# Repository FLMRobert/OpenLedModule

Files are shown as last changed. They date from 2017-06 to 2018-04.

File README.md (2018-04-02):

# OpenLedModule
OpenLedModule - an Open Hardware LED module project

The OpenLedModule project provides Open Hardware LED modules for everyone! 

With OpenLedModule, you can easily build your own lighting fixture - just follow these steps:

***

**Step 1**: Choose a basic LED lamp model that fits your needs

_Example_: choose [40FLATLED](https://github.com/FLMRobert/OpenLedModule/wiki/Lamps-40FLATLED) - a ceiling lamp that is as bright as two 60W light bulbs.

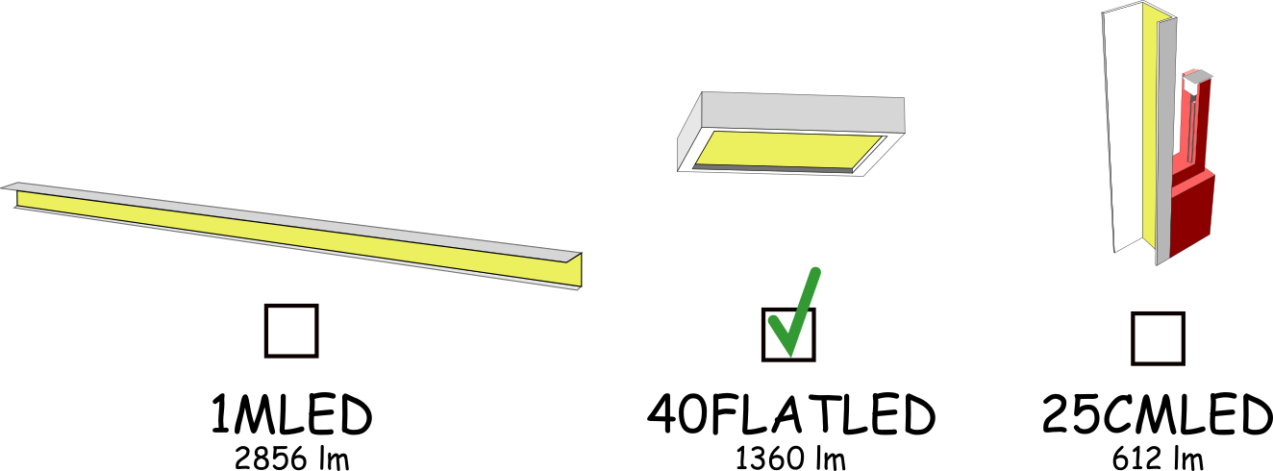
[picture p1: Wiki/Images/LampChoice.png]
Choose Lamp Model


***

**Step 2**: Check which LED Module is required to build the lamp model

_Example_: for lamp 40FLATLED, [Module 2](https://github.com/FLMRobert/OpenLedModule/wiki/Modules---Module-2) is required

***

**Step 3**: Order the required number of LED Modules from a PCB (circuit board) manufacturer of your choice

_Example_: [order](https://github.com/FLMRobert/OpenLedModule/wiki/Ordering-Overview) five Module 2 PCBs to build lamp 40FLATLED.

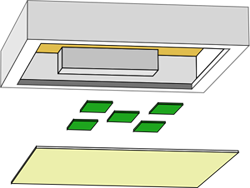
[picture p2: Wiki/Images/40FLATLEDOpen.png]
Check Lamp Module


***

**Step 4**: Order the parts (LEDs, resistors and pin headers) that are required for assembling the LED module

_Example_: the [Data Sheet of Module 2](https://github.com/FLMRobert/OpenLedModule/wiki/DataSheets-Modules-Module-2) lists all parts that are required for module assembly. For Module 2 you need to order eight [OSRAM Duris E5](https://github.com/FLMRobert/OpenLedModule/wiki/LEDs-OSRAM-Duris-E5) LEDs and one 30 Ohm resistor. This totals to 40 LEDs and five resistors for the five modules of lamp 40FLATLED. In addition to that you need nine pin headers that are required for connecting the module connector cables. 

***

**Step 5**: Solder your LED modules  
If you don't have reflow soldering equipment: go to a makerspace of your choice and solder it there.
Many makerspaces own a temperature-controlle "pizza oven" for reflow soldering.
With this oven, you can finalize your OpenLedModules.

***

**Step 6**: Assemble your LED lamp  
Get all the material that is required for your lamp model.

_Example_: for lamp 40FLATLED you need a power source (constant power source), an IKEA picture frame, some lasercut parts and other mounting material and cables. See [the data sheet](https://github.com/FLMRobert/OpenLedModule/wiki/DataSheets-Lamps-40FLATLED) of lamp 40FLATLED for the complete bill of materials.

***

## Motivation

You can buy cheap LED lamps in every hardware store, but many of the lamps you get there are just cheap crap.

Commercial LED lamps tend to break down after a short time and in many cases you have to throw away the whole lamp
just because only one little part of it is broken.

The solution for this problem is: **simply build your own LED lamp!**
If a part of your self made lamp breaks down: just fix that part.

* If one LED breaks: fix the LED. 
* If the whole LED module breaks: replace it.
* If the power supply breaks: replace it.

It's easy - believe me. 
If your are not able to fix it on your own: ask a friend or go to the hackerspace around the corner.

That's what the OpenLedModule project is about: we provide basic LED lamp designs that work,
while making sure that these LED lamps can also be easily maintained.

## History

The OpenLedModule project was initiated by [blinkgestalten](http://www.blinkgestalten.de/) 

## License

The OpenLedModule project is licensed under a CC BY-SA 4.0 License.
See LicenseCC_BY-SA_4.0.txt for license details or follow [this link](https://creativecommons.org/licenses/by-sa/4.0/legalcode).

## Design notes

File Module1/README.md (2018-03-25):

# OpenLedModule Module 1

## Overview 

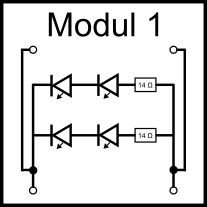
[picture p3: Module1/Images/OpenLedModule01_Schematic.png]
Module 1 Schematic

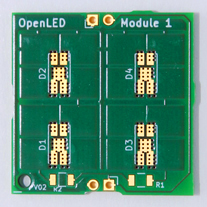
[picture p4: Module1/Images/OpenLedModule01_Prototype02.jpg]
Module 1 PCB

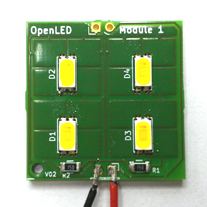
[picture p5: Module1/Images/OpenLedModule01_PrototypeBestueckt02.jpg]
Module 1 Assembled


The idea behind Module 1 was to use it for workshops where you can learn how to build your own LED lamp
by using a reflow soldering oven. So Module 1 is a good starting point if you want to build your first LED lamp.

Of course you can also use Module 1 for building your very personal torch light if you want. 

Module 1 is designed to work with battery power (6 AA rechargeable batteries).
You need to chain Module 1 three times in order to get the correct electrical current
per LED. 

Don't use less than three modules, otherwise you will destroy the LEDs.
Don't use more than three modules, ortherwise your LEDs will remain dark.
Use three of them. Really. It's true.

## Parts

* **LED:** 4 x Osram Duris E5 GW JDSTS2.EM
* **Resistor:** 2 x 14 Ohm

## Electric Characteristics

Module 1 is designed for 

* 7,2 V (voltage of six AA rechargeable batteries)
* 720 mA (typical current of six AA rechargeable batteries)
* typical current per parallel LED: 100 - 120 mA

## Light Characteristics

* Luminous Flux per Module: 204 lm (4 LEDs)
* Luminous Flux per LED: 51 lm (@ 2,95 V / 100 mA)
 
## Module 1 Applications

* LED Hand Lamp

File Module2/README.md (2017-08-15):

# OpenLedModule Module 2

## Overview 

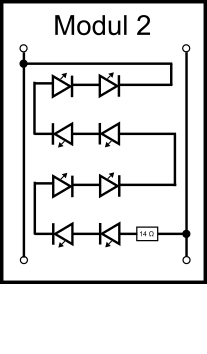
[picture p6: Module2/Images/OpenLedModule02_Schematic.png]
Module 2 Schematic

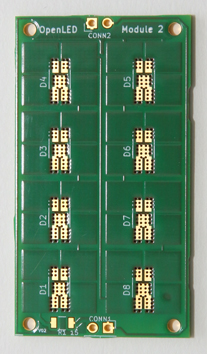
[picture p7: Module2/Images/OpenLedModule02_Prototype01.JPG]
Module 2 PCB

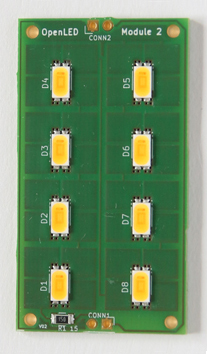
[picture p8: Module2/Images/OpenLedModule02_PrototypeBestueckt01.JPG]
Module 2 Assembled


The idea for Module 2 was to use it for standard LED lamp projects.
The module can be used for creating a LED lamp that replaces one 60 W light bulb 
(i.e. a "standard ceiling light") or to replace three 60 W light bulbs
(i.e. the "standard living room ceiling light").

Module 2 is designed to work with a constant current source of 350 mA or 700 mA.

Using a 350 mA current source corresponds ot the "one 60 W light bulb" mode:
With a 350 mA current source, you need to chain Module 2 five times 
in order to get the correct electrical current per LED.

Using a 700 mA current source corresponds ot the "three 60 W light bulbs" mode:
With a 700 mA current source, you need to chain Module 2 sevent times 
in order to get the correct electrical current per LED.

You should stick to these recommendations in order to not destroy the LEDs.

## Parts

* **LED:** 8 x Osram Duris E5 GW JDSTS2.EM
* **Resistor:** 1 x 15 Ohm

## Electric Characteristics

Module 2 is designed for operation with a 350 mA current source

* five chained modules
* 22,8 V (8 * 2,85 V) (voltage of eight serial LEDs)
* 350 mA current source
* typical current per parallel LED: 70 mA

Module 2 is designed for operation with a 700 mA current source

* seven chained modules
* 23,6 V (8 * 2,95 V) (voltage of eight serial LEDs)
* 700 mA current source
* typical current per parallel LED: 100 mA

## Light Characteristics

350 mA current source
* Total Luminous Flux: 1360 lm (5 Modules)
* Luminous Flux per Module: 272 lm (8 LEDs)
* Luminous Flux per LED: 34 lm (@ 2,85 V / 70 mA)

700 mA current source
* Total Luminous Flux: 2856 lm (7 Modules)
* Luminous Flux per Module: 408 lm (8 LEDs)
* Luminous Flux per LED: 51 lm (@ 2,95 V / 100 mA)
 
## Module 2 Applications

* Standard Ceiling Light
* Powerful Ceiling Light

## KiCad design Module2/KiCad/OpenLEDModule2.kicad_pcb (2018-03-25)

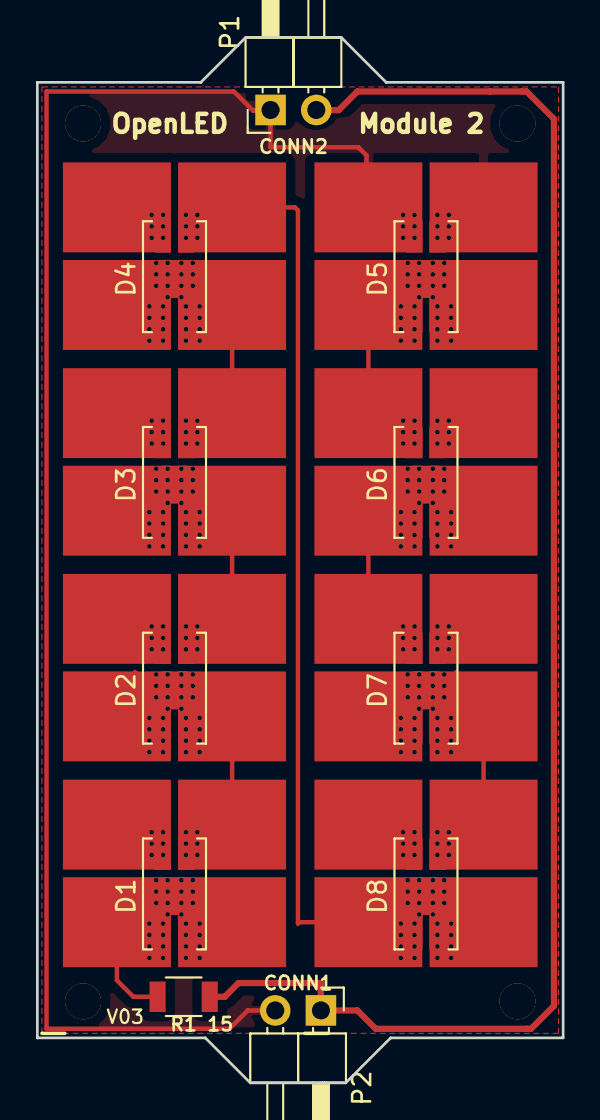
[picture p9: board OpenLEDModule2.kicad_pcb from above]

Board: 2 copper layers, 29.2 x 58.1 mm, 11 parts (0 on the bottom side), 10 nets.

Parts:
D1, D2, D3, D4, D5, D6, D7, D8: LED; LED_OsramDURIS_E5_JDSTS2EM
P1: CONN2; Pin_Header_Angled_1x02_Pitch2.54mm
P2: CONN1; Pin_Header_Angled_1x02_Pitch2.54mm
R1: 15; R_1206

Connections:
+24V: P1.2, P2.1, R1.1
GND: D5.1, P1.1, P2.2
unnamed: D1.1, D2.2
unnamed: D1.2, R1.2
unnamed: D2.1, D3.2
unnamed: D3.1, D4.2
unnamed: D4.1, D8.2
unnamed: D5.2, D6.1
unnamed: D6.2, D7.1
unnamed: D7.2, D8.1

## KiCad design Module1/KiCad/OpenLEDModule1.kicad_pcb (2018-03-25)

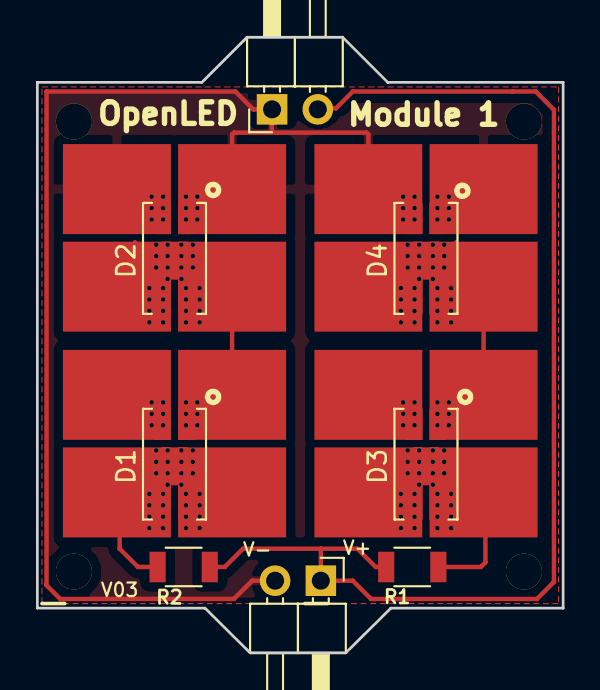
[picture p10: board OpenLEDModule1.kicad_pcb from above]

Board: 2 copper layers, 29.2 x 34.2 mm, 9 parts (1 on the bottom side), 6 nets.

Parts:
D1, D2, D3, D4: LED; LED_OsramDURIS_E5_JDSTS2EM
P1: CONN2; Pin_Header_Angled_1x02_Pitch2.54mm
P2: CONN1; Pin_Header_Angled_1x02_Pitch2.54mm
QRCODE: LOGO; qrcode_olm_inverse2
R1, R2: 15; R_1206

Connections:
+24V: P1.2, P2.1, R1.1, R2.1
GND: D2.1, D4.1, P1.1, P2.2
unnamed: D1.1, D2.2
unnamed: D1.2, R2.2
unnamed: D3.1, D4.2
unnamed: D3.2, R1.2

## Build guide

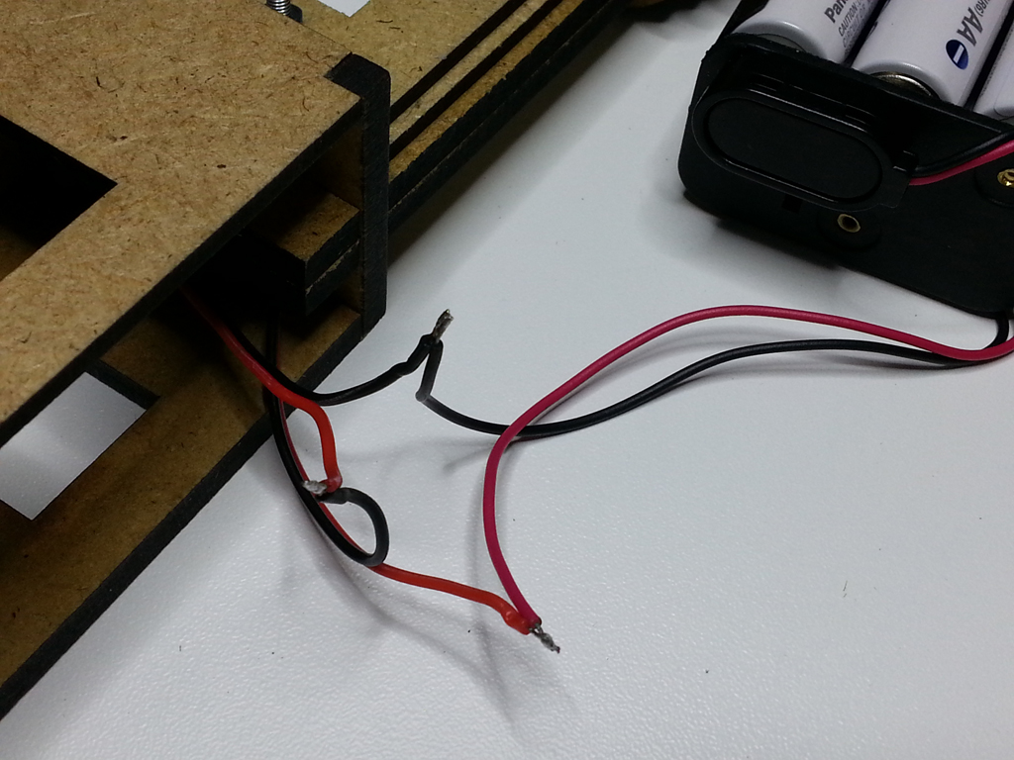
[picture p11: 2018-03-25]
Lamp25CMLED/Images/Assembly/32.jpg

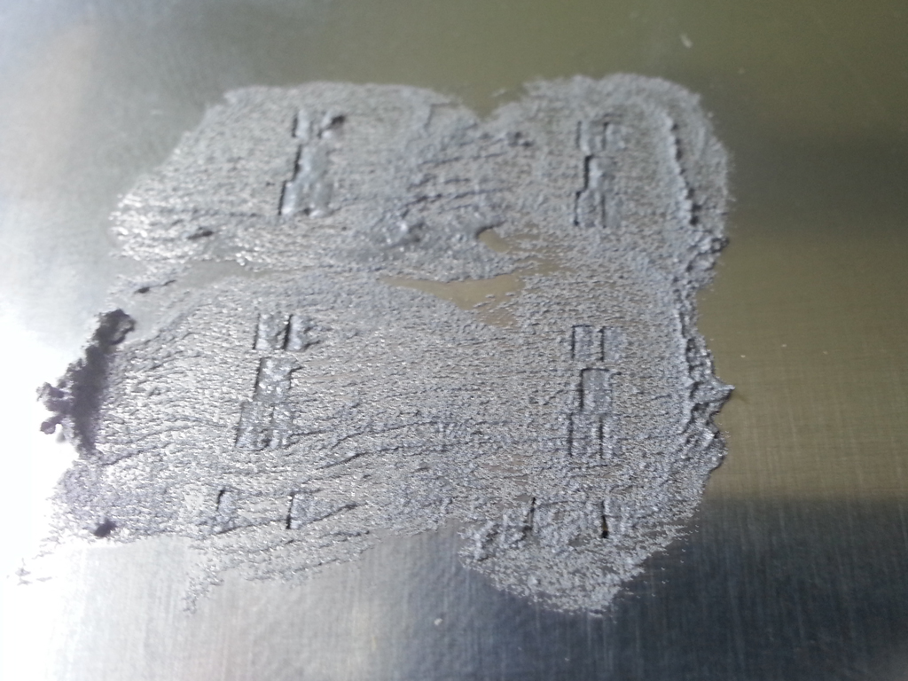
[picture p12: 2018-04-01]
Module1/Images/Assembly/03b.jpg

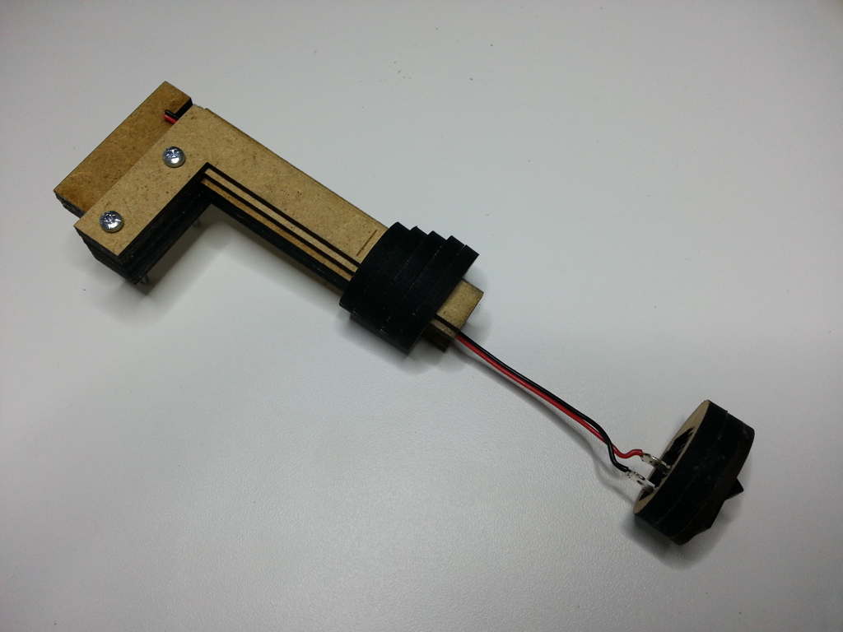
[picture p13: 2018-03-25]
Lamp25CMLED/Images/Assembly/19.jpg

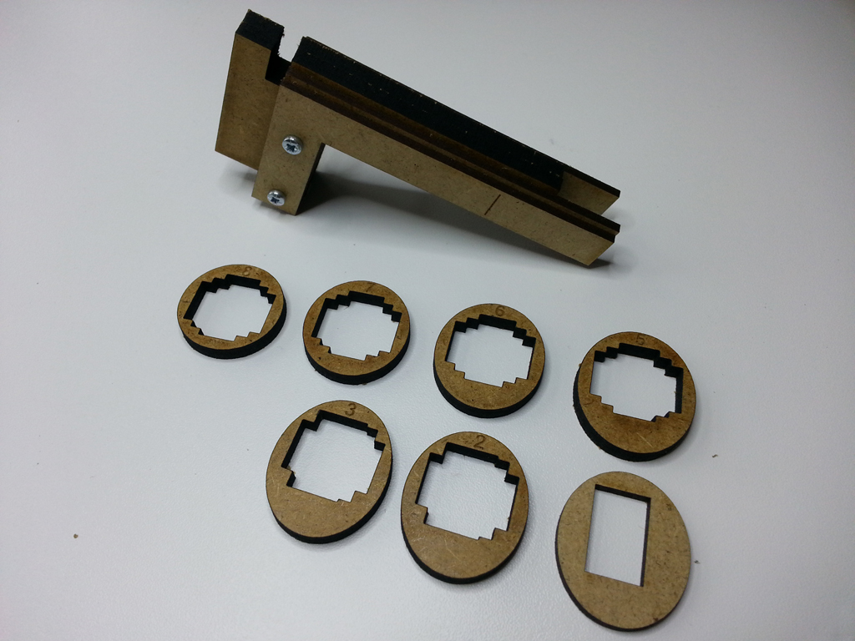
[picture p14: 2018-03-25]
Lamp25CMLED/Images/Assembly/11.jpg

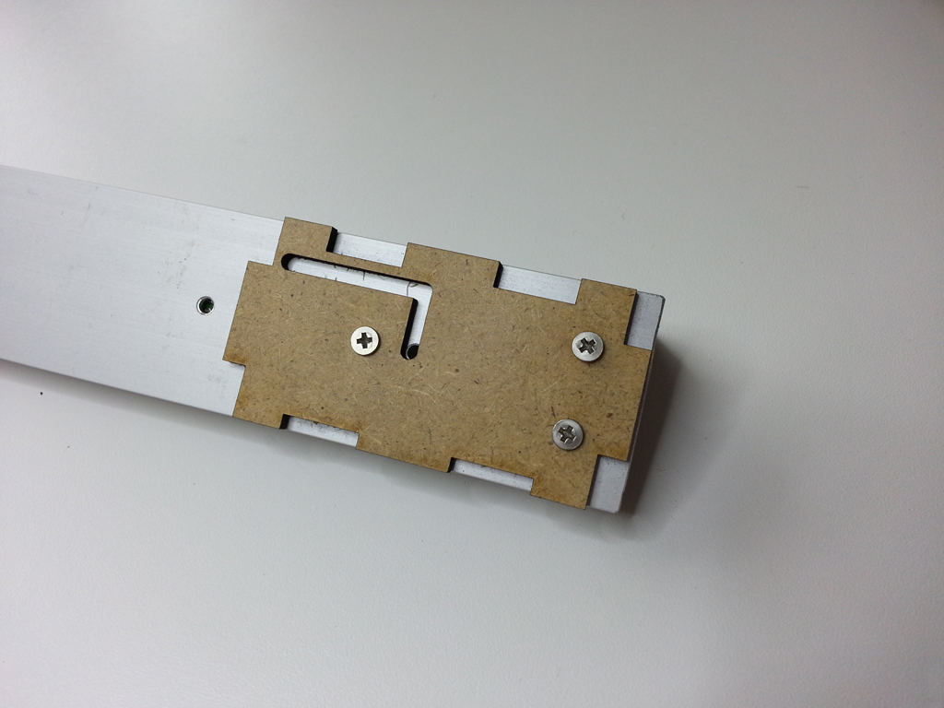
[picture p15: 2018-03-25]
Lamp25CMLED/Images/Assembly/03.jpg

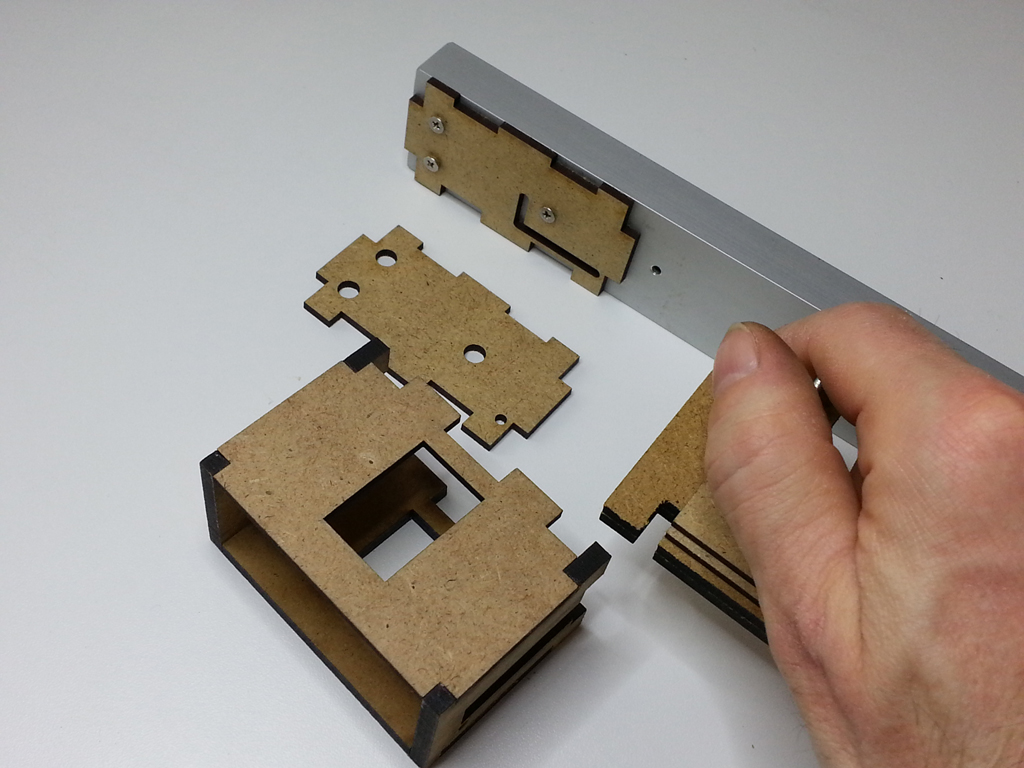
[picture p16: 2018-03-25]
Lamp25CMLED/Images/Assembly/20.jpg

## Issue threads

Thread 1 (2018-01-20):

Module1: Board V02 is not long enough - no header support

FLMRobert, 2018-01-20:
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

Board Module1 V02 is not long enough to support the headers.
Soldering the headers is therefore harder than it should be.
Request: enlarge board Module1.

FLMRobert, 2018-03-24:
Fixed in release 1.0.1

Closed 2018-03-24.

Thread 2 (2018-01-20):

Module2: Board V02 is not long enough - no header support

FLMRobert, 2018-01-20:
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

Board Module2 V02 is not long enough to support the headers.
Soldering the headers is therefore harder than it should be.
Request: enlarge board Module2.

FLMRobert, 2018-03-24:
Fixed in release 1.0.1

Closed 2018-03-24.

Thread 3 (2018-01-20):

Module1: Board V02 has only one hole - three holes are missing

FLMRobert, 2018-01-20:
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

Board Module1 V02 has only one hole.
Request: there should be four holes for more mounting options.

FLMRobert, 2018-03-24:
Fixed in release 1.0.1

Closed 2018-03-24.

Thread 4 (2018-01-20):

Module1: Board V02 polarity text at header is missing

FLMRobert, 2018-01-20:
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

Board Module1 V02 has no text at the header that indicates the polarity.
Request: add clearly visible text "+" and "-" to indicate polarity.

FLMRobert, 2018-03-24:
Fixed in release 1.0.1

Closed 2018-03-24.

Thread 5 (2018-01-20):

Module1: Board V02 is not protected against incorrect polarity of power supply

FLMRobert, 2018-01-20:
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

Board Module1 V02 is not protected against attaching a power supply with inverted polarity.
Request: extend Module1 by protection against inverted polarity.

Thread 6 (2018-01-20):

Module2: Board V02 is not protected against incorrect polarity of power supply

FLMRobert, 2018-01-20:
Board Module2 V02 is not protected against attaching a power supply with inverted polarity.
Request: extend Module2 by protection against inverted polarity.

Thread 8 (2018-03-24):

Module 1: Board should contain a marker indicating the correct LED orientation

FLMRobert, 2018-03-24:
Workshop feedback:
The Osram DURIS LED has a little black spot in the yellow area.
It might be helpful to add a round marker on the PCP layout near the LED pads
which indicates how to orient the LED i.e. where the little black spot should be located.

FLMRobert, 2018-03-24:
Fixed in release 1.0.1

Closed 2018-03-24.

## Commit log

2017-04-16 Initial checkin of Module1
    [OpenLEDModule1.kicad_pcb, OpenLEDModule1.sch]
2017-04-16 Fixed issue with wrong size of cooling copper surfaces on back side.
    [OpenLEDModule1.kicad_pcb]
2017-04-16 Initial checkin of Module 2
    [OpenLEDModule2.kicad_pcb, OpenLEDModule2.sch]
2017-04-16 Moved files to KiCad subfolder
    [OpenLEDModule2.kicad_pcb, OpenLEDModule2.sch]
2017-04-17 Added GND filling on Module 1/2. Added Gerbers.
    [OpenLEDModule1.kicad_pcb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]
2017-04-17 Fixed layers in pads of LED footprint.
    [OpenLEDModule1.kicad_pcb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]
2017-05-01 Several fixes to resolve review comments (thermal via connections, cooling pads, footprint, past and mask layers, resistors, holes, tracks)
    [OpenLEDModule1.kicad_pcb, OpenLEDModule1.sch, OpenLEDModule2.kicad_pcb]
2017-05-01 Final fixes (cleared F.Mask setting for cooling pads)
    [OpenLEDModule1.kicad_pcb, OpenLEDModule2.kicad_pcb]
2018-01-27 Added Resistor Icon for BOM
2018-01-29 Added icons for 25CMLED BOM
2018-01-29 Added icons for 40FLATLED BOM
2018-01-29 Added missing 40FLATLED BOM icon
2018-01-29 Added 1MLED BOM icons
2018-01-29 Changed file type of 1MLED BOM icon
2018-01-29 Added icons for 1MLED BOM
2018-03-18 Added 25CMLED lasercuts (V6)
2018-03-24 Fixed issues #1 (header supports), #3 (four holes), #4 (polarity text). Added enhancment #8 (LED orientation marker)
    [OpenLEDModule1.kicad_pcb]
2018-03-24 Fixed issue #2 (header support)
    [OpenLEDModule2.kicad_pcb]
2018-03-25 25CMLED assembly instruction images
2018-03-25 Added further 25CMLED assembly instruction images
2018-04-01 Added Module 1 assembly instruction images
